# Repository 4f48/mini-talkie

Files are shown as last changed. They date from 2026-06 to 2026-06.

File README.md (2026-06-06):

# mini-talkie

A little 868 MHz walkie-talkie with LoRa radio for long ranges with built-in battery and USB-C charging.

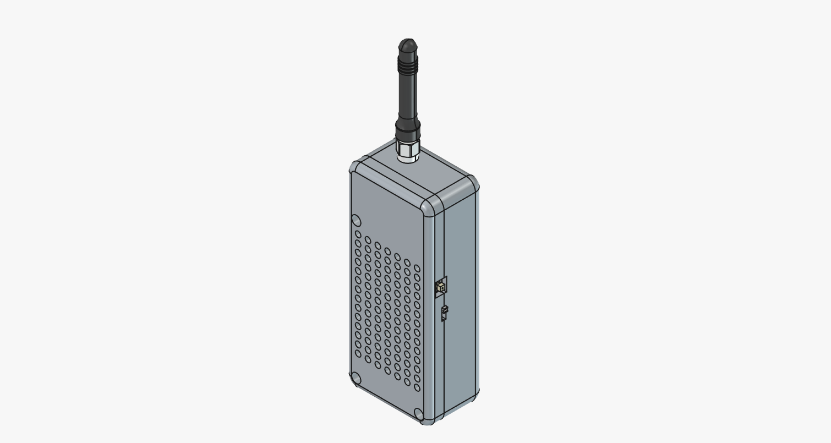
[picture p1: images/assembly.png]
3D render of the complete project with all parts, including the antenna.


### Features:
- 100% off-grid. Works anywhere!
- Long range: multiple kilometers in ideal conditions
- Long battery life: 1200 mAh lithium-polymer battery
- Convenient USB-C charging
- Swappable antenna: use any 868 MHz antenna you want
- Multiple modes: push-to-talk, voice activation
- Small size: fits in your pockets

### Usage:
1. Turn it on using the switch on the left.
2. Start talking! Use the push-to-talk button, or switch to voice activation and talk hands free.
3. Battery low? Plug it in to your regular phone charger.

## Why?
All the walkie-talkies I tried before have too short range, have too many fancy features I would never use, or are very expensive. This walkie-talkie is unique in the way that it uses LoRa radio, making it operate through exceptional ranges. It's also dead simple: no screen, no dials. It doesn't have many extra features, but the ones it has just work. It is also not very expensive to build. It's great for hiking so nobody gets lost, or multiple-car road trips to keep in contact with the other cars without phone calls.

## Assembly
You can actually build a mini-talkie for yourself. All you need is the PCB, SMD components, a speaker, an antenna and internal antenna cable. Below is a rough guide to making one.

### 1. PCB and components

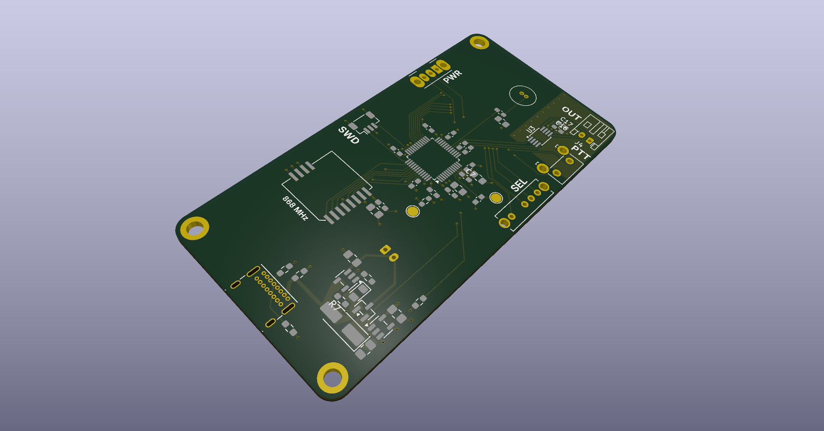
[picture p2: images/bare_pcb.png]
3D render of a green circuit board needed for assembly.


The printed circuit board has to be manufactured somewhere. I recommend [Aisler](https://aisler.net) or [JLCPCB](https://jlcpcb.com), but any similar services work. You can find the source files for the PCB in [/pcb](./pcb). Make sure to order the PCBA (assembly) service if you are not comfortable soldering smaller sized components.

You also need some other components ordered. Check out the [Bill of Materials](./bom.csv) which includes links to help you order them easily.

| Component | MPN | Reference | Qty | Link |
|---|---|---|-----|---|
| 0603 2.2 µF capacitor | CC0603KRX7R5BB225  | C1,C2 | 2 | https://www.digikey.hu/short/4rjpq33n |
| 0603 100 nF capacitor | CC0603KRX7R5BB104  | C3,C4,C5,C6,C7,C9,C14,C18,C19 | 9 | https://www.digikey.hu/short/dt7hb4qj |
| 0805 10 µF capacitor | CL21A106KQFNNNG | C8,C10,C11,C12,C13,C20 | 6 | https://www.digikey.hu/short/tvz058r0 |
| 0603 1 µF capacitor | CL10A105KQ8NNNC | C15,C16 | 2 | https://www.digikey.hu/short/z9n48j83 |
| 0603 10 µF capacitor | GRM188R60J106KE47D | C17 | 1 | https://www.digikey.hu/short/4j9w29qw |
| Schottky diode | B0520WS-7-F | D1 | 1 | https://www.digikey.hu/short/ht5bt73v |
| 0805 orange LED | LTST-C170KFKT | D2 | 1 | https://www.digikey.hu/short/45p872b7 |
| 0603 ferrite bead 600 Ω @100 MHz | BLM18KG601SN1D | FB1 | 1 | https://www.digikey.hu/short/0mqd98np |
| SWD connector | BM03B-SRSS-TB | J1 | 1 | https://www.digikey.hu/short/5p581w55 |
| USB-C receptacle | USB4085-GF-A | J2 | 1 | https://www.digikey.hu/short/b77q7dpn |
| battery connector | S2B-PH-K-S | J3 | 1 | https://www.digikey.hu/short/4j185jz8 |
| speaker connector | S2B-PH-K-S | J4 | 1 | https://www.digikey.hu/short/4j185jz8 |
| microphone | TOW-3050P-B-R | MK1 | 1 | https://www.digikey.hu/short/pvdf25rr |
| MOSFET | AO3401A | Q1 | 1 | https://www.digikey.hu/short/8rwf7289 |
| 0603 10 kΩ resistor | RC0603FR-0710KL | R1,R4,R5,R6 | 4 | https://www.digikey.hu/short/b31dpcpj |
| 0603 5.1 kΩ resistor | RC0603FR-075K1L | R2,R3,R7 | 3 | https://www.digikey.hu/short/q0d4nh3t |
| 0805 1 kΩ resistor | ESR10EZPF1001 | R8 | 1 | https://www.digikey.hu/short/5hnt9d3r |
| SP3T sliding right-angle switch | OS103011MA7QP1C | SW1 | 1 | https://www.digikey.hu/short/jz8f2558 |
| SPDT sliding right-angle switch | OS102011MA1QN1 | SW2 | 1 | https://www.digikey.hu/short/1v0t4jtn |
| SPST right-angle pushbutton switch | B3F-3152 | SW3 | 1 | https://www.digikey.hu/short/0rj93f0h |
| microcontroller | STM32H503CBT6 | U1 | 1 | https://www.digikey.hu/short/n7f3hf4p |
| LoRa chipset | 114993390 | U2 | 1 | https://www.digikey.hu/short/prpdvndd |
| amplifier | PAM8302AASCR | U3 | 1 | https://www.digikey.hu/short/0pzv4hpb |
| battery charger | MCP73831T-2ACI/OT  | U4 | 1 | https://www.digikey.hu/short/wfqbhvzq |
| 3.3V LDO voltage regulator | RT9080-33GJ5 | U5 | 1 | https://www.digikey.hu/short/2h9019td |
| speaker | 4227 | - | 1 | https://www.digikey.hu/short/59fcjjq4 |
| antenna | GHX-325ASA3B | - | 1 | https://www.digikey.hu/short/fqjjtd0b |
| antenna cable | 18568 | - | 1 | https://www.digikey.hu/short/jn7jd79m |
| battery | AKY0622 | - | 1 | https://www.tme.eu/hu/details/aky-lp883440/akkumulatorok/akyga-battery/aky0622/ |
| 2-pin JST PH cable | 4714 | - | 1 | https://www.digikey.hu/short/8mm8t1d7 |

Total cost of components: $38,82/unit (excl. taxes)

### 2. Printed parts

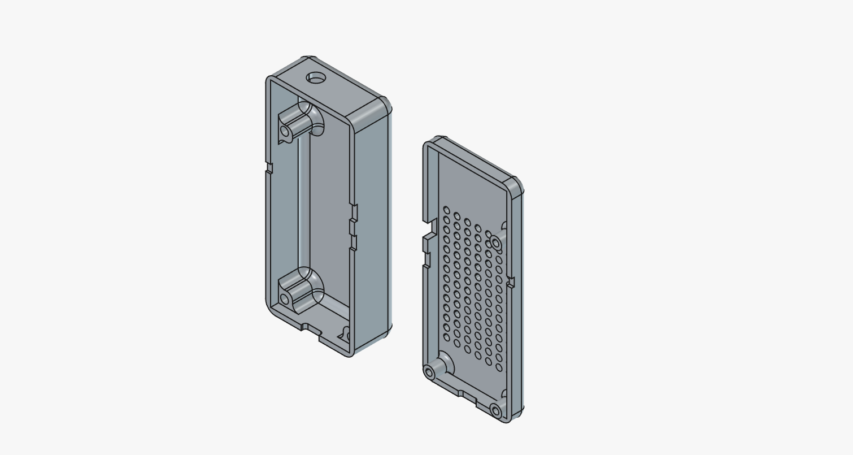
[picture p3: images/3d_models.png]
The 3D printed parts needed for assembly seen alongside each other in a 3D render.


mini-talkie's enclosure is made from 2 parts. These have to be made on a 3D printer. If you don't have access to a 3D priner, explore services like [JLC3DP](https://jlc3dp.com) that print and ship the parts to you.

You can find the source files in [/3d](./3d) and exported models [/3d/exports](./3d/exports) for printing in STEP format.

### 3. Soldering

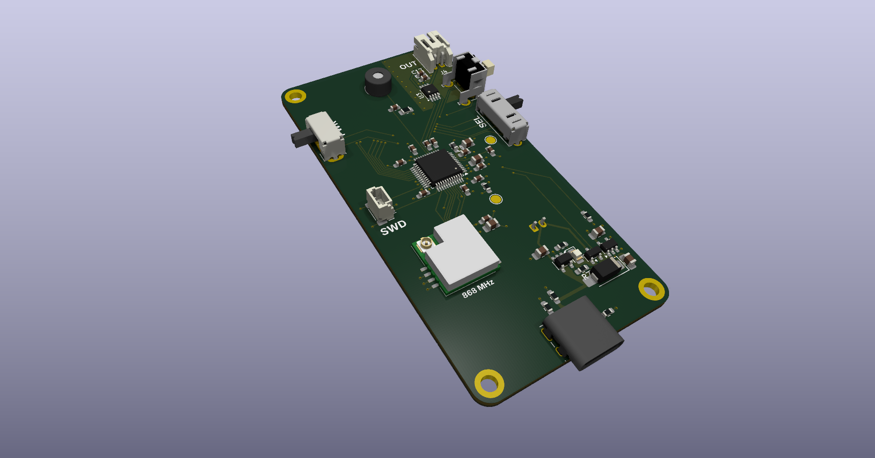
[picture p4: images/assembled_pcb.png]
The same printed circuit board as before, but with components such as resistors and capacitors soldered on the surface.


A fine-tipped soldering iron and some flux is needed for this part. Refer to the PCB source files in [/pcb](./pcb) as a reference for placing the correct parts.

Skip this step if you ordered your PCBs assembled (PCBA).

In addition, you need to remove the included connectors from the speaker and battery and solder on the 2-pin JST PH connectors you ordered instead. You need to do this even if you ordered a PCBA.

### 4. Programming

You need a Raspberry Pi Zero (2) or a separate debugger. Connect it to the SWD port on the circuit board and load the firmware from [/firmware](./firmware).

> TODO: Complete this part with instructions once the code is actually done.

### 5. Assembly
1. Insert 3 threaded inserts in the correct holes on the bottom enclosure. Appropriate tools are needed for this step.
2. Install the antenna cable using the included washers and nut.
3. Peel the protective layer off the adhesive on the speaker and stick it on the top enclosure, behind the speaker grille, but in a way that it won't obstruct the microphone.
4. Drop the battery into the compartment under where the PCB goes and plug it into the board.
5. Place the board on the bottom enclosure so that the battery connector is facing down.
6. Plug in the speaker to the board, and put the top enclosure on the bottom, then screw all the M2.5 screws into the top enclosure. Those 3 screws hold everything together, so make sure they are secure.
7. Compete the build by installing your SMA antenna on the top.

## Fallout Zine
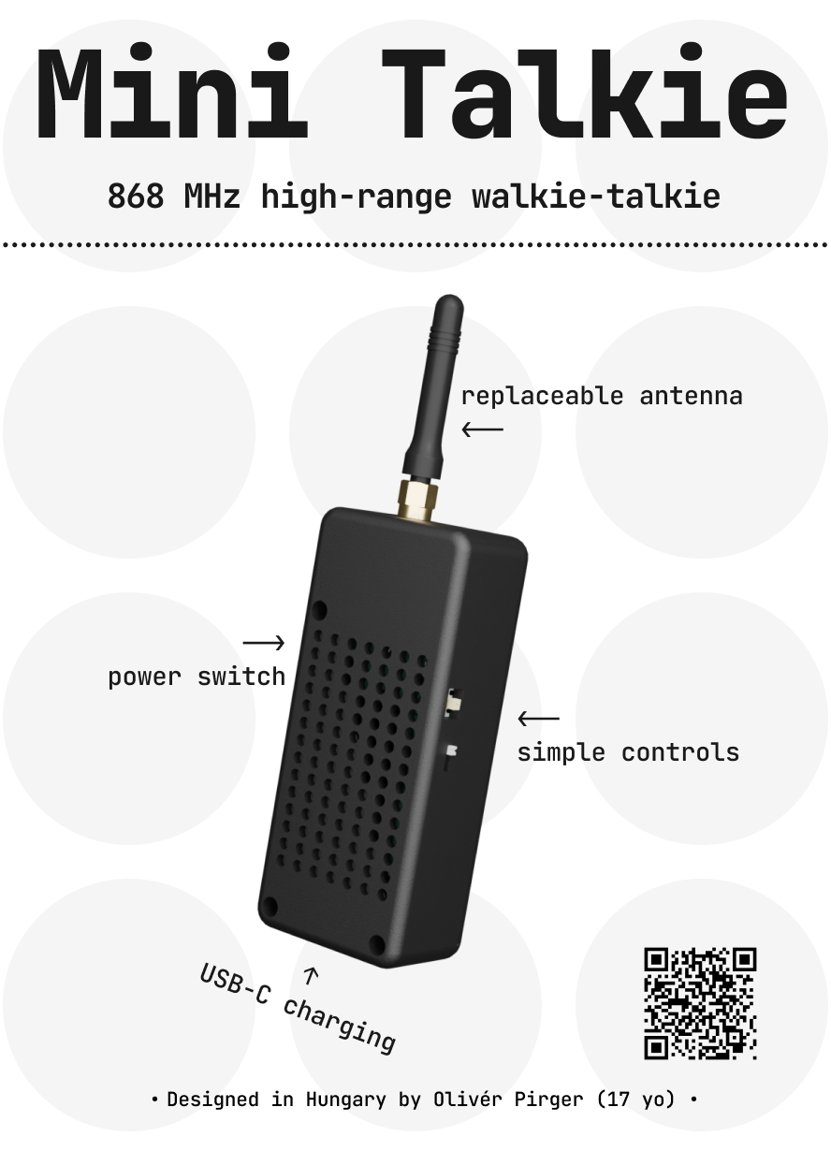
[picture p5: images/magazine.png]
Mini Talkie Fallout Zine page


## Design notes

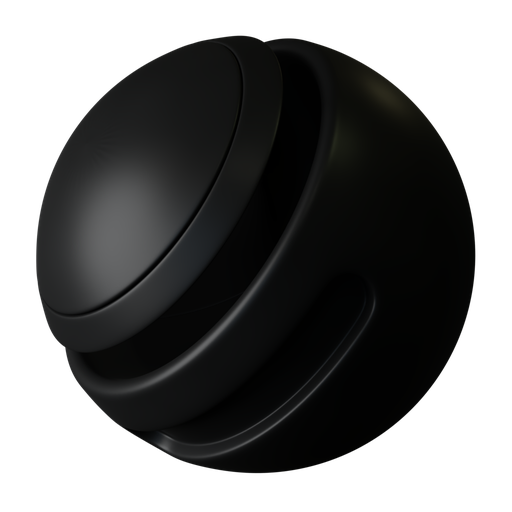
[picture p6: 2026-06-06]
3d/assets/materials/electronic-matte_d0cde993-10f6-4fa6-80ad-e8ae532fcb36/preview.png

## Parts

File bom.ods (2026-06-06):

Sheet: bom_new
Component | MPN | Reference | Qty | Link
0603 2.2 µF capacitor | CC0603KRX7R5BB225 | C1,C2 | 2 | https://www.digikey.hu/short/4rjpq33n
0603 100 nF capacitor | CC0603KRX7R5BB104 | C3,C4,C5,C6,C7,C9,C14,C18,C19 | 9 | https://www.digikey.hu/short/dt7hb4qj
0805 10 µF capacitor | CL21A106KQFNNNG | C8,C10,C11,C12,C13,C20 | 6 | https://www.digikey.hu/short/tvz058r0
0603 1 µF capacitor | CL10A105KQ8NNNC | C15,C16 | 2 | https://www.digikey.hu/short/z9n48j83
0603 10 µF capacitor | GRM188R60J106KE47D | C17 | 1 | https://www.digikey.hu/short/4j9w29qw
Schottky diode | B0520WS-7-F | D1 | 1 | https://www.digikey.hu/short/ht5bt73v
0805 orange LED | LTST-C170KFKT | D2 | 1 | https://www.digikey.hu/short/45p872b7
0603 ferrite bead 600 Ω @100 MHz | BLM18KG601SN1D | FB1 | 1 | https://www.digikey.hu/short/0mqd98np
SWD connector | BM03B-SRSS-TB | J1 | 1 | https://www.digikey.hu/short/5p581w55
USB-C receptacle | USB4085-GF-A | J2 | 1 | https://www.digikey.hu/short/b77q7dpn
battery connector | S2B-PH-K-S | J3 | 1 | https://www.digikey.hu/short/4j185jz8
speaker connector | S2B-PH-K-S | J4 | 1 | https://www.digikey.hu/short/4j185jz8
microphone | TOW-3050P-B-R | MK1 | 1 | https://www.digikey.hu/short/pvdf25rr
MOSFET | AO3401A | Q1 | 1 | https://www.digikey.hu/short/8rwf7289
0603 10 kΩ resistor | RC0603FR-0710KL | R1,R4,R5,R6 | 4 | https://www.digikey.hu/short/b31dpcpj
0603 5.1 kΩ resistor | RC0603FR-075K1L | R2,R3,R7 | 3 | https://www.digikey.hu/short/q0d4nh3t
0805 1 kΩ resistor | ESR10EZPF1001 | R8 | 1 | https://www.digikey.hu/short/5hnt9d3r
SP3T sliding right-angle switch | OS103011MA7QP1C | SW1 | 1 | https://www.digikey.hu/short/jz8f2558
SPDT sliding right-angle switch | OS102011MA1QN1 | SW2 | 1 | https://www.digikey.hu/short/1v0t4jtn
SPST right-angle pushbutton switch | B3F-3152 | SW3 | 1 | https://www.digikey.hu/short/0rj93f0h
microcontroller | STM32H503CBT6 | U1 | 1 | https://www.digikey.hu/short/n7f3hf4p
LoRa chipset | 114993390 | U2 | 1 | https://www.digikey.hu/short/prpdvndd
amplifier | PAM8302AASCR | U3 | 1 | https://www.digikey.hu/short/0pzv4hpb
battery charger | MCP73831T-2ACI/OT | U4 | 1 | https://www.digikey.hu/short/wfqbhvzq
3.3V LDO voltage regulator | RT9080-33GJ5 | U5 | 1 | https://www.digikey.hu/short/2h9019td
speaker | 4227 | - | 1 | https://www.digikey.hu/short/59fcjjq4
antenna | GHX-325ASA3B | - | 1 | https://www.digikey.hu/short/fqjjtd0b
antenna cable | 18568 | - | 1 | https://www.digikey.hu/short/jn7jd79m
battery | AKY0622 | - | 1 | https://www.tme.eu/hu/details/aky-lp883440/akkumulatorok/akyga-battery/aky0622/
2-pin JST PH cable | 4714 | - | 1 | https://www.digikey.hu/short/8mm8t1d7

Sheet: bom
Reference | Qty | Value | DNP | Exclude from BOM | Exclude from Board | Footprint | Datasheet | MPN
C1,C2 | 2 | 2.2u |  |  |  | Capacitor_SMD:C_0603_1608Metric_Pad1.08x0.95mm_HandSolder
C3,C4,C5,C6,C7,C9,C14,C18,C19 | 9 | 100n |  |  |  | Capacitor_SMD:C_0603_1608Metric_Pad1.08x0.95mm_HandSolder
C8,C10,C11,C12,C13,C20 | 6 | 10u |  |  |  | Capacitor_SMD:C_0805_2012Metric_Pad1.18x1.45mm_HandSolder
C15,C16 | 2 | 1u |  |  |  | Capacitor_SMD:C_0603_1608Metric_Pad1.08x0.95mm_HandSolder
C17 | 1 | 10u |  |  |  | Capacitor_SMD:C_0603_1608Metric_Pad1.08x0.95mm_HandSolder
D1 | 1 | PMEG3020EH |  |  |  | Diode_SMD:D_SMA_Handsoldering | https://assets.nexperia.com/documents/data-sheet/PMEG3020EH_EJ.pdf
D2 | 1 | ORANGE |  |  |  | LED_SMD:LED_0805_2012Metric_Pad1.15x1.40mm_HandSolder
FB1 | 1 | 600@100 |  |  |  | Inductor_SMD:L_0603_1608Metric_Pad1.05x0.95mm_HandSolder |  | BLM18KG601SN1D
J1 | 1 | SWD |  |  |  | Connector_JST:JST_SH_BM03B-SRSS-TB_1x03-1MP_P1.00mm_Vertical
J2 | 1 | USB_C_Receptacle_USB2.0_16P |  |  |  | Connector_USB:USB_C_Receptacle_GCT_USB4085 | https://www.usb.org/sites/default/files/documents/usb_type-c.zip
J3 | 1 | BATT |  |  |  | Connector_JST:JST_PH_S2B-PH-K_1x02_P2.00mm_Horizontal
J4 | 1 | SPEAKER |  |  |  | Connector_JST:JST_PH_S2B-PH-K_1x02_P2.00mm_Horizontal
MK1 | 1 | Microphone |  |  |  | Mini_Talkie:PUI_THT-2 | https://mm.digikey.com/Volume0/opasdata/d220001/medias/docus/5883/TOW-3050P-B-R.pdf | TOW-3050P-B-R
Q1 | 1 | AO3401A |  |  |  | Package_TO_SOT_SMD:SOT-23 | http://www.aosmd.com/pdfs/datasheet/AO3401A.pdf
R1,R4,R5,R6 | 4 | 10k |  |  |  | Resistor_SMD:R_0603_1608Metric_Pad0.98x0.95mm_HandSolder
R2,R3,R7 | 3 | 5.1k |  |  |  | Resistor_SMD:R_0603_1608Metric_Pad0.98x0.95mm_HandSolder
R8 | 1 | 1k |  |  |  | Resistor_SMD:R_0805_2012Metric_Pad1.20x1.40mm_HandSolder
SW1 | 1 | SW_SP3T |  |  |  | Mini_Talkie:CK_SW_SP3T_OS103011MA7QP1C |  | OS103011MA7QP1C
SW2 | 1 | SW_SPDT |  |  |  | Button_Switch_THT:SW_Slide_SPDT_Angled_CK_OS102011MA1Q |  | OS102011MA1QN1
SW3 | 1 | SW_SPST |  |  |  | Button_Switch_THT:SW_SPST_Omron_B3F-315x_Angled |  | B3F-3152
U1 | 1 | STM32H503CBTx |  |  |  | Package_QFP:LQFP-48_7x7mm_P0.5mm | https://www.st.com/resource/en/datasheet/stm32h503cb.pdf | STM32H503CBT6
U2 | 1 | Wio-SX1262 |  |  |  | Mini_Talkie:Seeed_SMD-12 | https://files.seeedstudio.com/products/SenseCAP/Wio_SX1262/Wio-SX1262_Module_Datasheet.pdf | 114993390
U3 | 1 | PAM8302AAS |  |  |  | Package_SO:MSOP-8_3x3mm_P0.65mm | https://www.diodes.com/assets/Datasheets/PAM8302A.pdf | PAM8302AASCR
U4 | 1 | MCP73831-2-OT |  |  |  | Package_TO_SOT_SMD:SOT-23-5 | http://ww1.microchip.com/downloads/en/DeviceDoc/20001984g.pdf | MCP73831T-2ACI/OT
U5 | 1 | RT9080 |  |  |  | Package_TO_SOT_SMD:TSOT-23-5 | https://www.richtek.com/SaveDownload.aspx?specid=RT9080 | RT9080-33GJ5

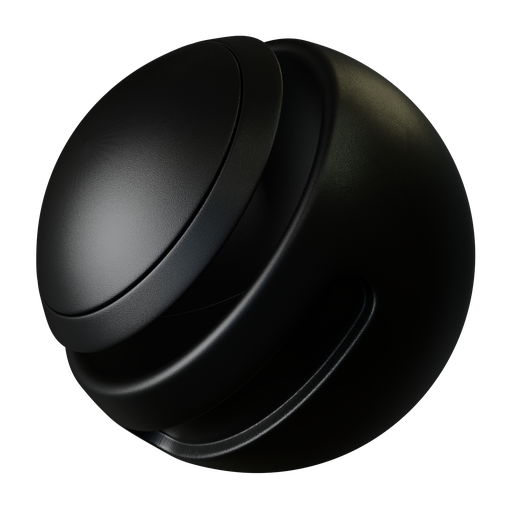
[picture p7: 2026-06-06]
3d/assets/materials/black-plastic_7241e7a9-cc3e-4f80-ab34-076465f5e7b7/preview.png

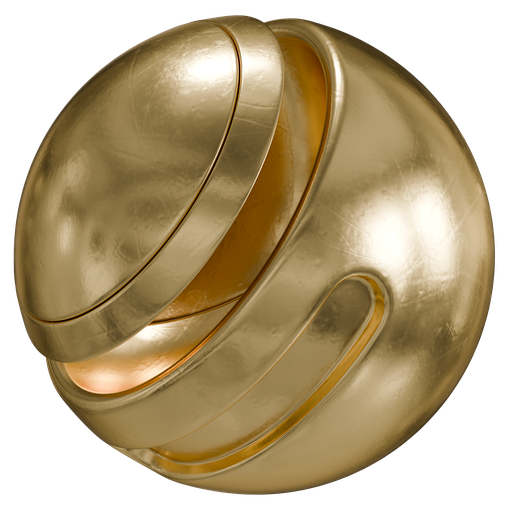
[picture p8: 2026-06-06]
3d/assets/materials/gold-metal-imper_c8b09f5b-229d-401b-b50c-7efede71810c/preview.png

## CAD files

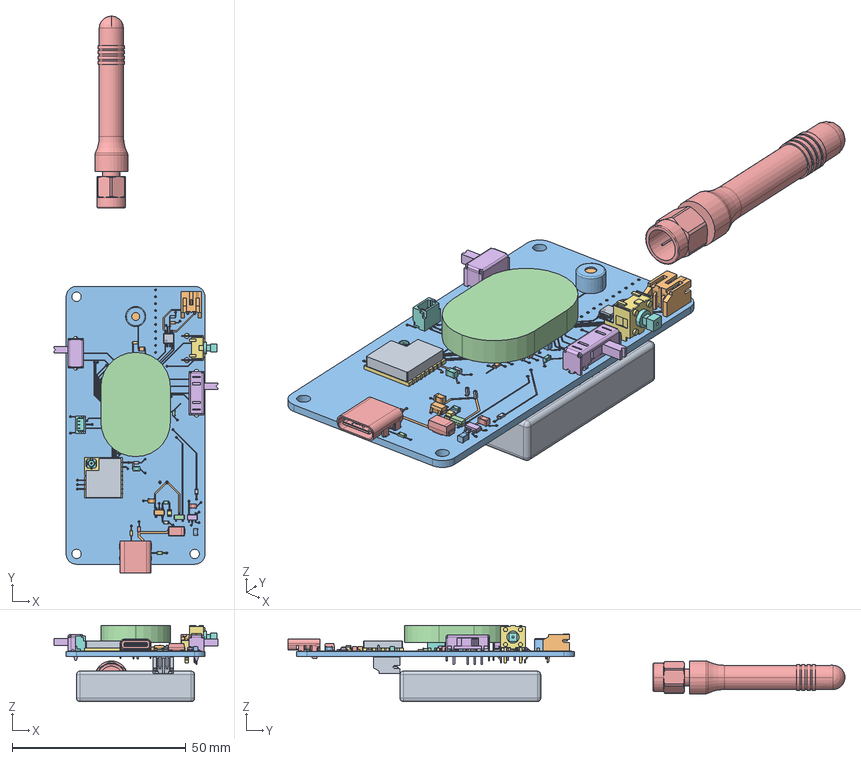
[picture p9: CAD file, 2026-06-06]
3d/Assembly.FCStd
47.1 x 160.3 x 22.0 mm
Battery_Placeholder
JST_S2B_PH_K002
C_0603_1608Metric028
R_0603_1608Metric014
C_0603_1608Metric030
SW_Slide_SPDT_Angled_CK_OS102011MA1Q002
User_Library-IPEX001
Extruded001
SOT-23-002
C_0603_1608Metric032
C_0805_2012Metric012
C_0603_1608Metric034
R_0603_1608Metric016
C_0805_2012Metric014
MSOP-8_3x3mm_P0.65mm002
C_0603_1608Metric036
C_0603_1608Metric038
C_0603_1608Metric040
USB_C_Receptacle_GCT_USB4087
TSOT-23-002
C_0603_1608Metric042
C_0603_1608Metric044
R_0603_1608Metric018
R_0805_2012Metric002
C_0805_2012Metric016
SOT-002
R_0603_1608Metric020
L_0603_1608Metric002
C_0603_1608Metric046
R_0603_1608Metric022
C_0805_2012Metric018
C_0603_1608Metric048
C_0805_2012Metric020
OS103011MA7QP1C002
C_0603_1608Metric050
R_0603_1608Metric024
R_0603_1608Metric026
C_0805_2012Metric022
C_0603_1608Metric052
C_0603_1608Metric054
D_SMA002
LQFP-48_7x7mm_P0.5mm002
LED_0805_2012Metric002
JST_SH_BM03B-SRSS-TB_1x03-1MP_P1.00mm_Vertical002
JST_S2B_PH_K003
mini-talkie_copper001
mini-talkie_PCB001
Speaker
APAMBJ-135

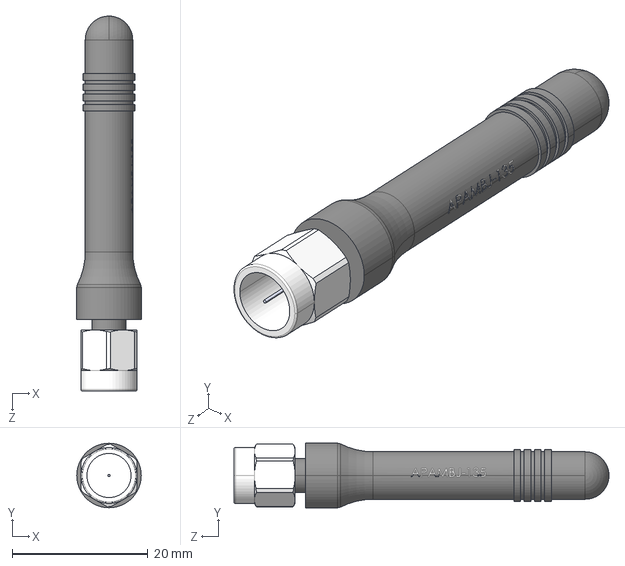
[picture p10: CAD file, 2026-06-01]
3d/assets/placeholder-antenna.STEP
9.50 x 9.50 x 55.2 mm

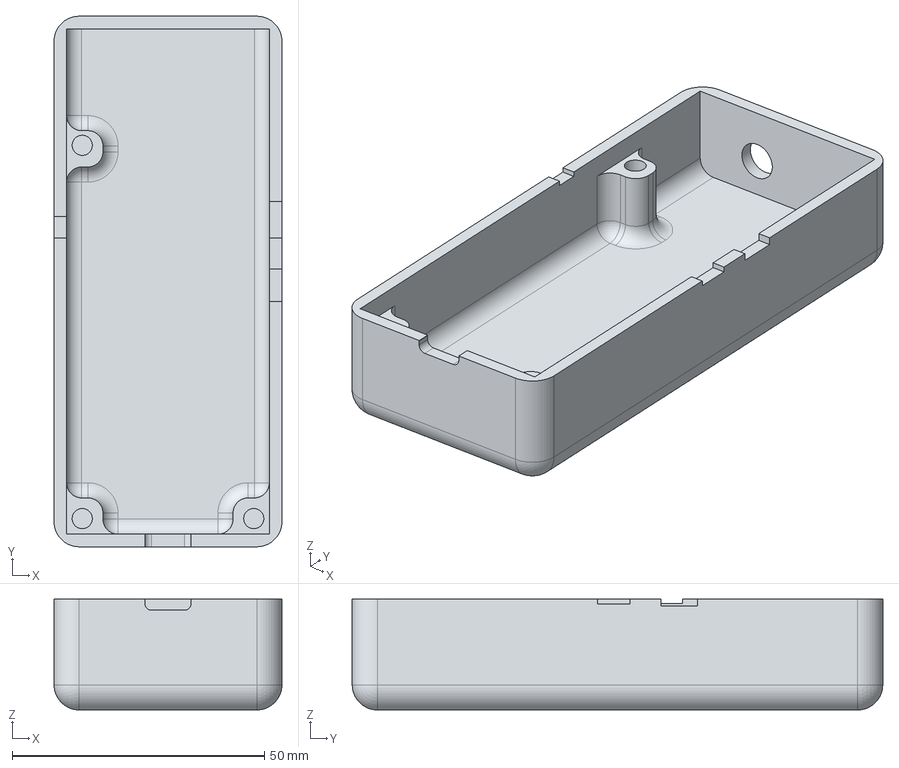
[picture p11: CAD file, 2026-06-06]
3d/exports/mini-talkie-bottom.step
45.2 x 105.2 x 22.0 mm

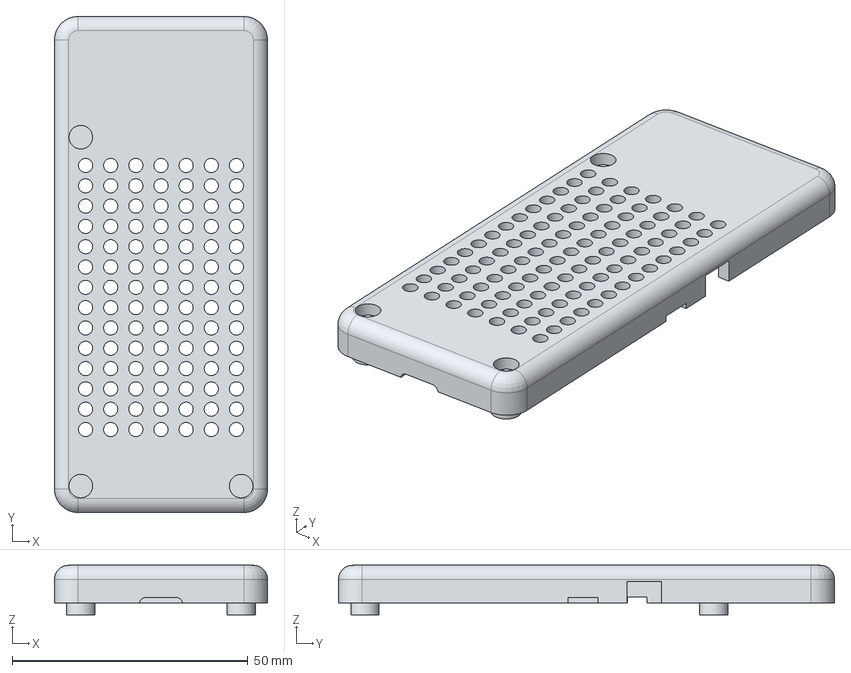
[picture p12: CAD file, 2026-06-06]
3d/exports/mini-talkie-top.step
45.2 x 105.2 x 10.5 mm

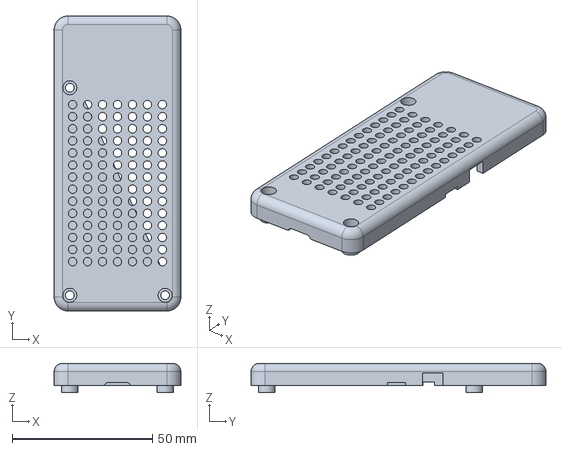
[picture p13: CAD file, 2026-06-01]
3d/Top.FCStd
45.2 x 105.2 x 10.5 mm

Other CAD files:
3d/Bottom.FCStd
3d/assets/materials/black-plastic_7241e7a9-cc3e-4f80-ab34-076465f5e7b7/black-plastic_6acbffe2-8be6-4458-9b88-4d81a32f724b.blend
3d/assets/materials/electronic-matte_d0cde993-10f6-4fa6-80ad-e8ae532fcb36/electronic-matte-plastic_cbf48e2c-4f99-4ea6-8944-e342aad152ed.blend
3d/assets/materials/gold-metal-imper_c8b09f5b-229d-401b-b50c-7efede71810c/gold-metal-imperfections_2K_03a4959b-e7d5-421b-ab6a-2c02d15ecdc7.blend
3d/assets/materials/procedural-pearl_386d3d08-9144-4145-881e-4b2d25c8202e/procedural-pearl-black-painted-plastic_1259bd7e-0b5d-4e1f-b9a1-3f4d8cb0f768.blend
3d/mini-talkie.blend

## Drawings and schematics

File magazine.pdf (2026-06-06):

# Mini Talkie

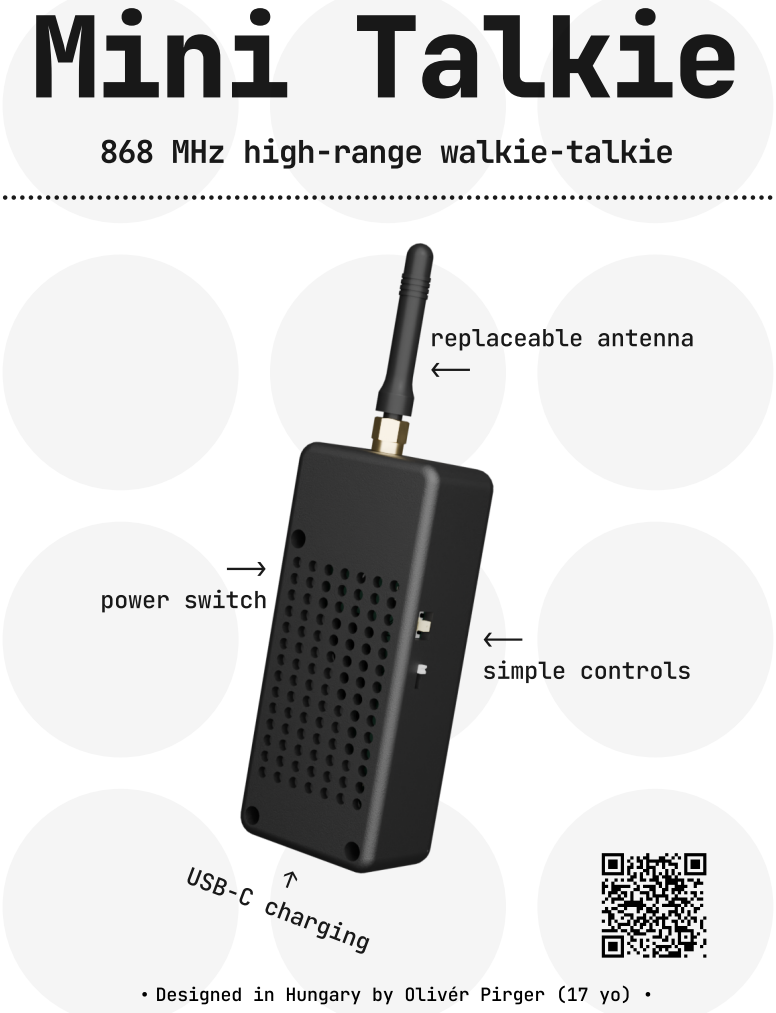
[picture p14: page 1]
replaceable antenna <--; --> power switch; <-- simple controls; USB-C charging ↑

868 MHz high-range walkie-talkie

Designed in Hungary by Olivér Pirger (17 yo) •

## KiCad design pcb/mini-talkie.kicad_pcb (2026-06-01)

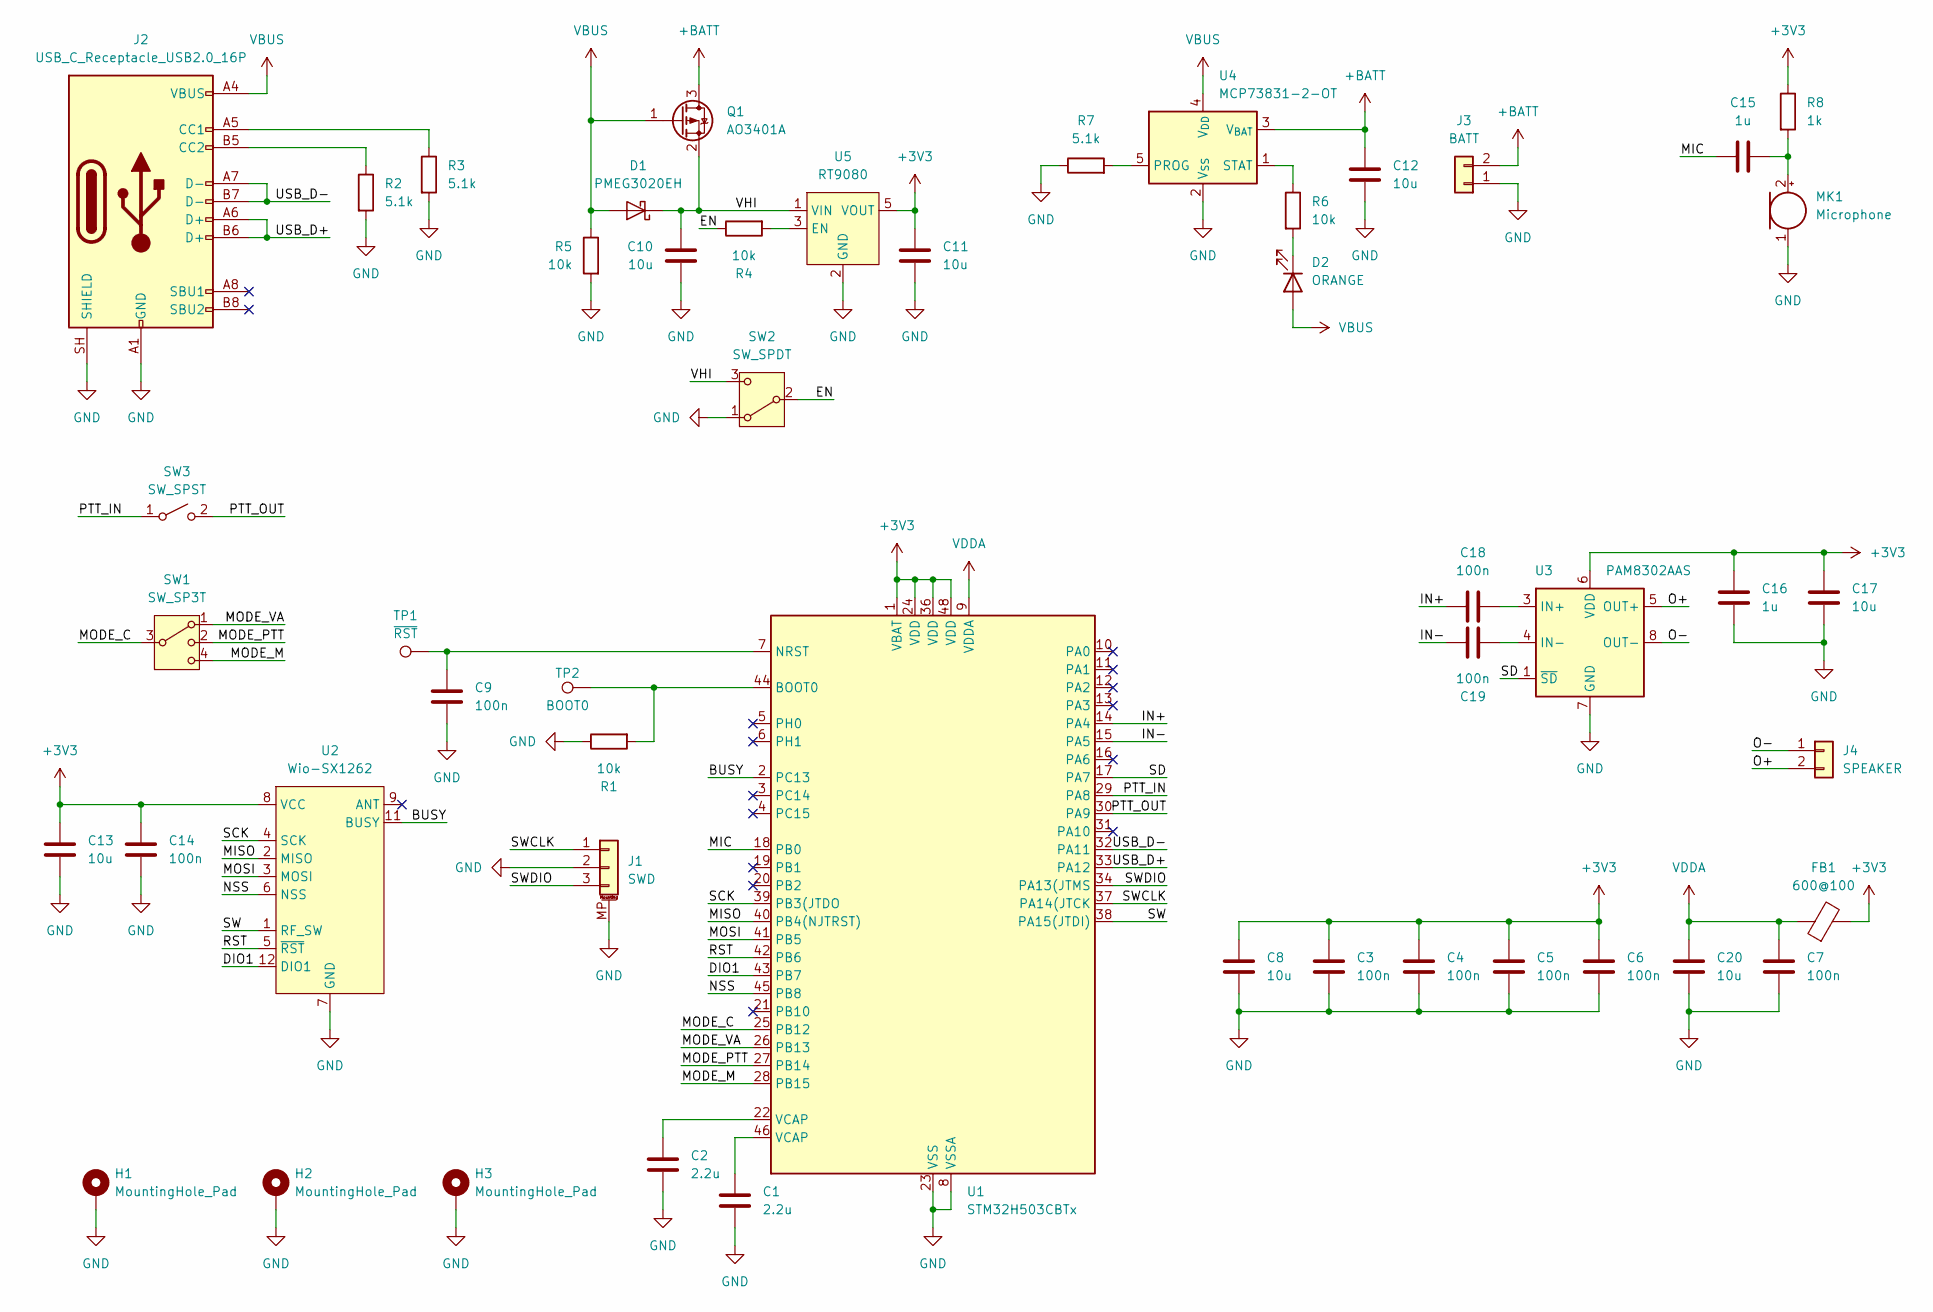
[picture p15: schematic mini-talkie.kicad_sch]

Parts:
C1, C2: 2.2u; C_0603_1608Metric_Pad1.08x0.95mm_HandSolder
C3, C4, C5, C6, C7, C9, C14, C18, C19: 100n; C_0603_1608Metric_Pad1.08x0.95mm_HandSolder
C8, C10, C11, C12, C13, C20: 10u; C_0805_2012Metric_Pad1.18x1.45mm_HandSolder
C15, C16: 1u; C_0603_1608Metric_Pad1.08x0.95mm_HandSolder
C17: 10u; C_0603_1608Metric_Pad1.08x0.95mm_HandSolder
D1: PMEG3020EH; D_SMA_Handsoldering
D2: ORANGE; LED_0805_2012Metric_Pad1.15x1.40mm_HandSolder
FB1: 600@100; L_0603_1608Metric_Pad1.05x0.95mm_HandSolder; MPN BLM18KG601SN1D
H1, H2, H3: MountingHole_Pad; MountingHole_2.7mm_M2.5_ISO7380_Pad
J1: SWD; JST_SH_BM03B-SRSS-TB_1x03-1MP_P1.00mm_Vertical
J2: USB_C_Receptacle_USB2.0_16P; USB_C_Receptacle_GCT_USB4085
J3: BATT; JST_PH_S2B-PH-K_1x02_P2.00mm_Horizontal
J4: SPEAKER; JST_PH_S2B-PH-K_1x02_P2.00mm_Horizontal
MK1: Microphone; PUI_THT-2; MPN TOW-3050P-B-R
Q1: AO3401A; SOT-23
R1, R4, R5, R6: 10k; R_0603_1608Metric_Pad0.98x0.95mm_HandSolder
R2, R3, R7: 5.1k; R_0603_1608Metric_Pad0.98x0.95mm_HandSolder
R8: 1k; R_0805_2012Metric_Pad1.20x1.40mm_HandSolder
SW1: SW_SP3T; CK_SW_SP3T_OS103011MA7QP1C; MPN OS103011MA7QP1C
SW2: SW_SPDT; SW_Slide_SPDT_Angled_CK_OS102011MA1Q; MPN OS102011MA1QN1
SW3: SW_SPST; SW_SPST_Omron_B3F-315x_Angled; MPN B3F-3152
TP1: ~{RST}; TestPoint_Pad_D2.0mm
TP2: BOOT0; TestPoint_Pad_D2.0mm
U1: STM32H503CBTx; LQFP-48_7x7mm_P0.5mm; MPN STM32H503CBT6
U2: Wio-SX1262; Seeed_SMD-12; MPN 114993390
U3: PAM8302AAS; MSOP-8_3x3mm_P0.65mm; MPN PAM8302AASCR
U4: MCP73831-2-OT; SOT-23-5; MPN MCP73831T-2ACI/OT
U5: RT9080; TSOT-23-5; MPN RT9080-33GJ5

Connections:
+3V3: C3.1, C4.1, C5.1, C6.1, C8.1, C11.1, C13.1, C14.1, C16.1, C17.1, FB1.2, R8.1, U1.1 (VBAT), U1.24 (VDD), U1.36 (VDD), U1.48 (VDD), U2.8 (VCC), U3.6 (VDD), U5.5 (VOUT)
+BATT: C12.1, J3.2, Q1.3 (D), U4.3 (V_{BAT})
/BUSY: U1.2 (PC13), U2.11 (BUSY)
/DIO1: U1.43 (PB7), U2.12 (DIO1)
/EN: R4.1, SW2.2 (B)
/IN+: C18.1, U1.14 (PA4)
/IN-: C19.1, U1.15 (PA5)
/MIC: C15.1, U1.18 (PB0)
/MISO: U1.40 (PB4(NJTRST)), U2.2 (MISO)
/MODE_C: SW1.3, U1.25 (PB12)
/MODE_M: SW1.4, U1.28 (PB15)
/MODE_PTT: SW1.2, U1.27 (PB14)
/MODE_VA: SW1.1, U1.26 (PB13)
/MOSI: U1.41 (PB5), U2.3 (MOSI)
/NSS: U1.45 (PB8), U2.6 (NSS)
/O+: J4.2, U3.5 (OUT+)
/O-: J4.1, U3.8 (OUT-)
/PTT_IN: SW3.1 (A), U1.29 (PA8)
/PTT_OUT: SW3.2 (B), U1.30 (PA9)
/RST: U1.42 (PB6), U2.5 (~RST)
/SCK: U1.39 (PB3(JTDO), U2.4 (SCK)
/SD: U1.17 (PA7), U3.1 (~SD)
/SW: U1.38 (PA15(JTDI)), U2.1 (RF_SW)
/SWCLK: J1.1, U1.37 (PA14(JTCK)
/SWDIO: J1.3, U1.34 (PA13(JTMS)
/USB_D+: J2.A6 (D+), J2.B6 (D+), U1.33 (PA12)
/USB_D-: J2.A7 (D-), J2.B7 (D-), U1.32 (PA11)
/VHI: C10.1, D1.1 (K), Q1.2 (S), SW2.3 (C), U5.1 (VIN)
GND: C1.1, C2.1, C3.2, C4.2, C5.2, C6.2, C7.2, C8.2, C9.2, C10.2, C11.2, C12.2, C13.2, C14.2, C16.2, C17.2, C20.2, H1.1 (1_1), H2.1 (1_1), H3.1 (1_1), J1.2, J1.MP (MountPin), J2.A1 (GND), J2.A12 (GND), J2.B1 (GND), J2.B12 (GND), J2.SH (SHIELD), J3.1, MK1.1 (-), R1.1, R2.2, R3.2, R5.2, R7.1, SW2.1 (A), U1.8 (VSSA), U1.23 (VSS), U1.35 (VSS), U1.47 (VSS), U2.7 (GND), U2.10 (GND), U3.7 (GND), U4.2 (V_{SS}), U5.2 (GND), U5.4 (GND)
unnamed: C1.2, U1.46 (VCAP)
unnamed: C2.2, U1.22 (VCAP)
unnamed: D2.1 (K), R6.2
unnamed: J2.A5 (CC1), R3.1
unnamed: J2.B5 (CC2), R2.1
unnamed: C15.2, MK1.2 (+), R8.2
unnamed: R1.2, TP2.1 (1_1), U1.44 (BOOT0)
unnamed: C9.1, TP1.1 (1_1), U1.7 (NRST)
unnamed: C18.2, U3.3 (IN+)
unnamed: C19.2, U3.4 (IN-)
unnamed: R7.2, U4.5 (PROG)
unnamed: R6.1, U4.1 (STAT)
unnamed: R4.2, U5.3 (EN)
VBUS: D1.2 (A), D2.2 (A), J2.A4 (VBUS), J2.A9 (VBUS), J2.B4 (VBUS), J2.B9 (VBUS), Q1.1 (G), R5.1, U4.4 (V_{DD})
VDDA: C7.1, C20.1, FB1.1, U1.9 (VDDA)

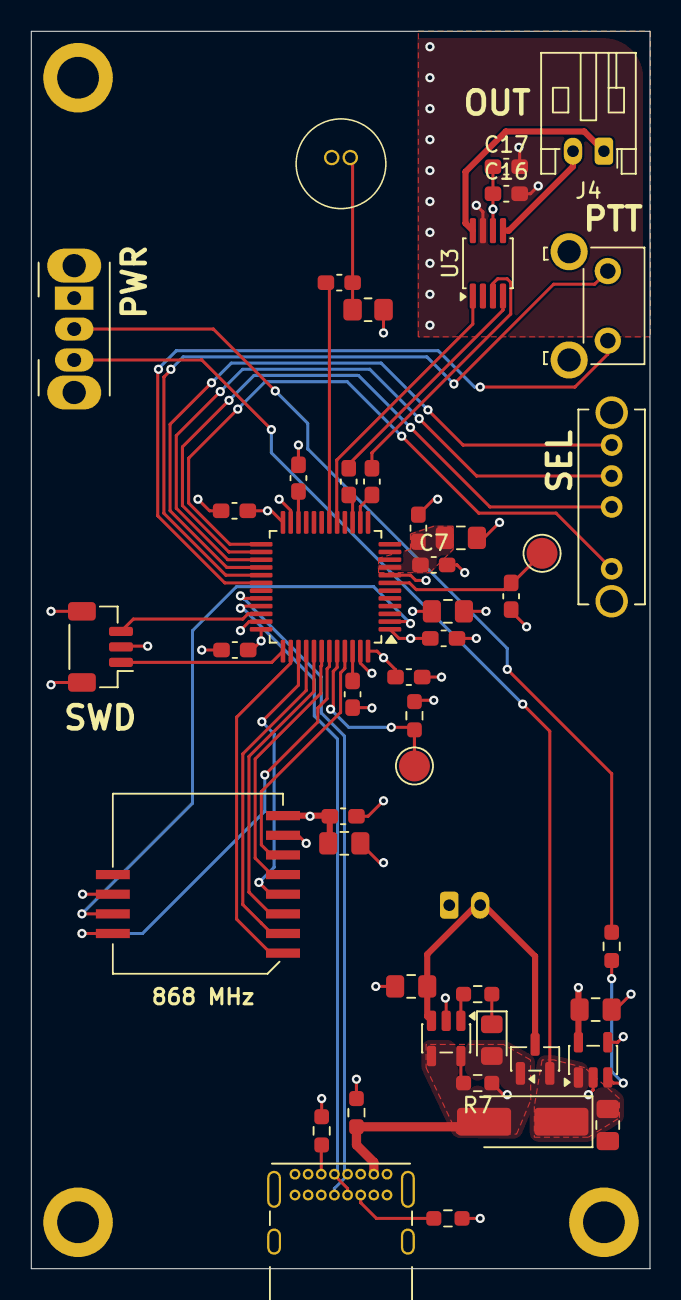
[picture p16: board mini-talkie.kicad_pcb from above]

Board: 4 copper layers, 40.0 x 80.0 mm, 50 parts (1 on the bottom side), 44 nets.

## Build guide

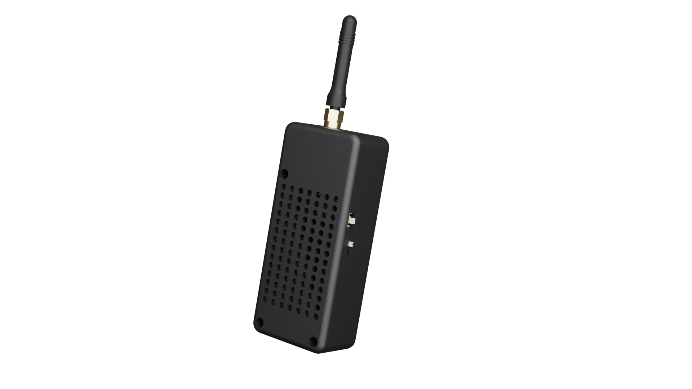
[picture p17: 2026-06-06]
images/assembly_3d_render.png

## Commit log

2026-05-23 mcu, radio, mic footprints
    [mini-talkie.kicad_pcb, mini-talkie.kicad_sch]
2026-05-24 switches, power supply
    [mini-talkie.kicad_sch]
2026-05-25 schematic almost done
    [mini-talkie.kicad_pcb, mini-talkie.kicad_sch]
2026-05-26 get started with layout
    [mini-talkie.kicad_pcb, mini-talkie.kicad_sch]
2026-05-27 pcb routing
    [mini-talkie.kicad_pcb, mini-talkie.kicad_sch]
2026-05-28 silkscreen, 3d models
    [mini-talkie.kicad_pcb]
2026-05-28 start bom
    [mini-talkie.kicad_sch]
2026-05-30 start enclosure
    [Assembly.FCStd, Bottom.FCStd]
2026-05-31 cutouts, speaker grille
    [Assembly.FCStd, Bottom.FCStd, Top.FCStd]
2026-06-01 continue 3d model
    [Assembly.FCStd, Bottom.FCStd, Top.FCStd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]
2026-06-02 docs, images
    [Assembly.FCStd]
2026-06-02 start compiling complete bom
    [bom.csv, bom.ods]
2026-06-03 continue bom
    [bom.csv, bom.ods, mini-talkie.kicad_sch]
2026-06-06 add bom preview and estimated cost
    [bom.ods]
2026-06-06 add zine
    [Assembly.FCStd, black-plastic_6acbffe2-8be6-4458-9b88-4d81a32f724b.blend, electronic-matte-plastic_cbf48e2c-4f99-4ea6-8944-e342aad152ed.blend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]
2026-06-06 add exports
    [mini-talkie-bottom.step, mini-talkie-top.step]

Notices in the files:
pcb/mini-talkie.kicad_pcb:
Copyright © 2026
